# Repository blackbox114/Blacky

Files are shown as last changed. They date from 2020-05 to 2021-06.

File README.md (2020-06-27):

# Blacky

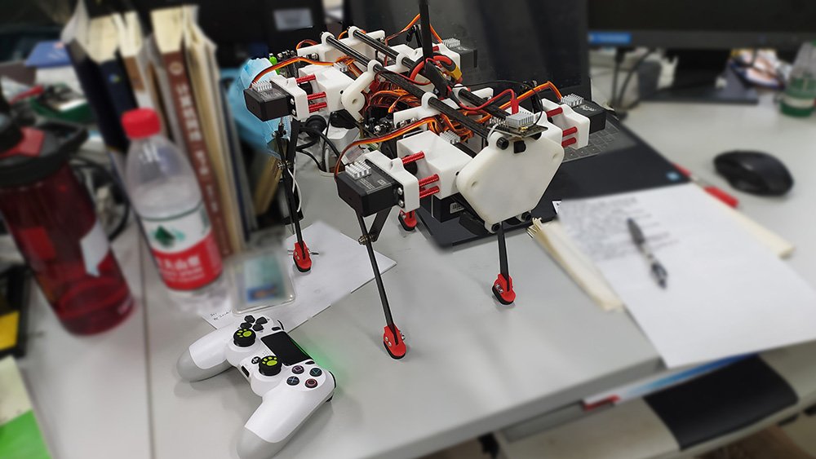
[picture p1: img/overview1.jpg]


The project originated from [StanfordPupper](https://github.com/stanfordroboticsclub/StanfordQuadruped) ，Designed to improve some structures to achieve better performance, and learn the algorithms used in the pupper. Thanks to Nathan and his team for their work, it ’s really great. Feel free to [raise an issue](https://github.com/blackbox114/blacky/issues/new/choose)  or email me at chen.junfei@nexuslink.cn

### Bilibili

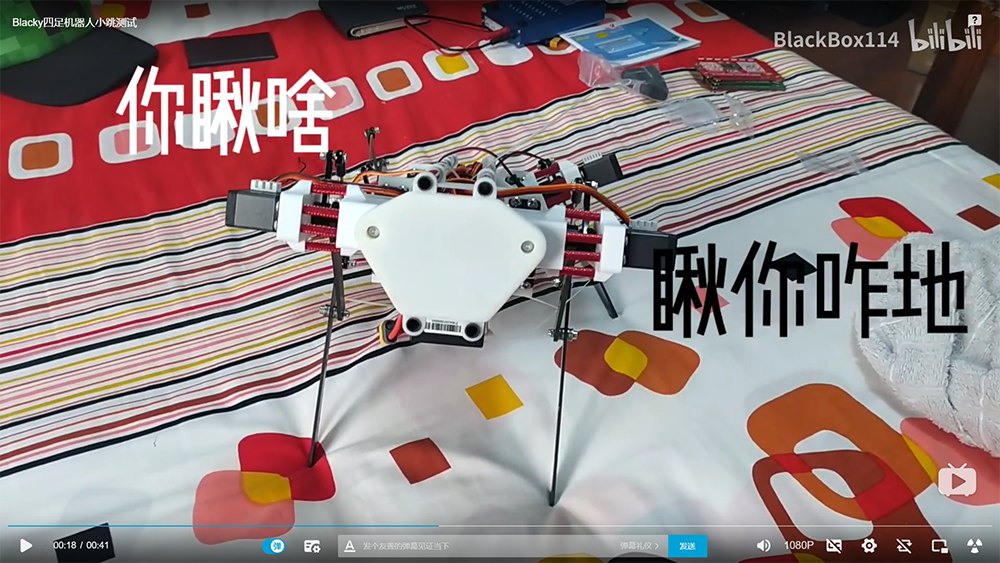
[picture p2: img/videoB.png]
(https://www.bilibili.com/video/BV1B54y1D7uH/)


### YouTube

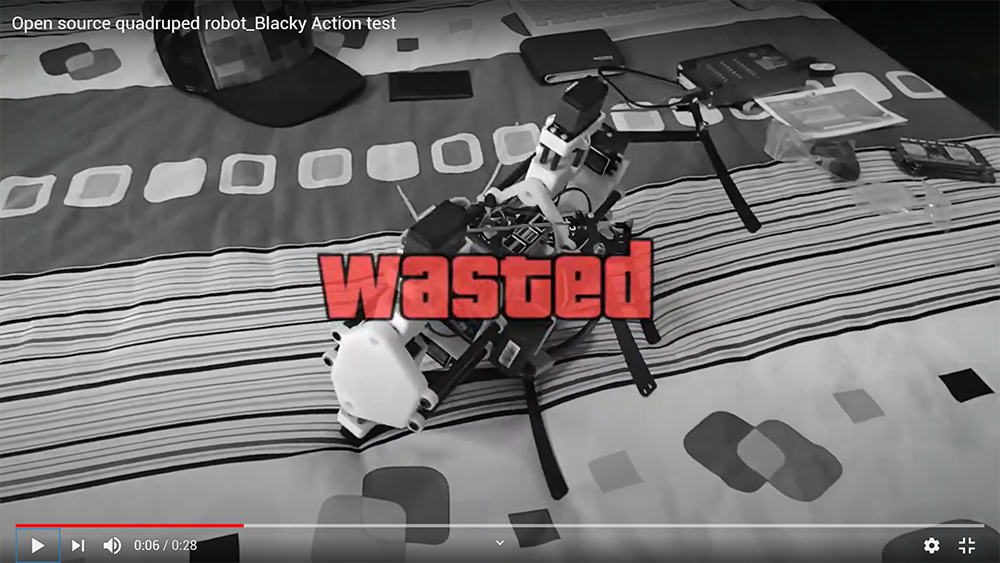
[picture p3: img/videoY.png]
(https://www.youtube.com/watch?v=VOyvlLOYNlo)


ps:正在本地化和推出中文教程 

### current condition 
Now calibrating hip and leg.

### Overview
12Dof, use pi4 and CLS6336servo.

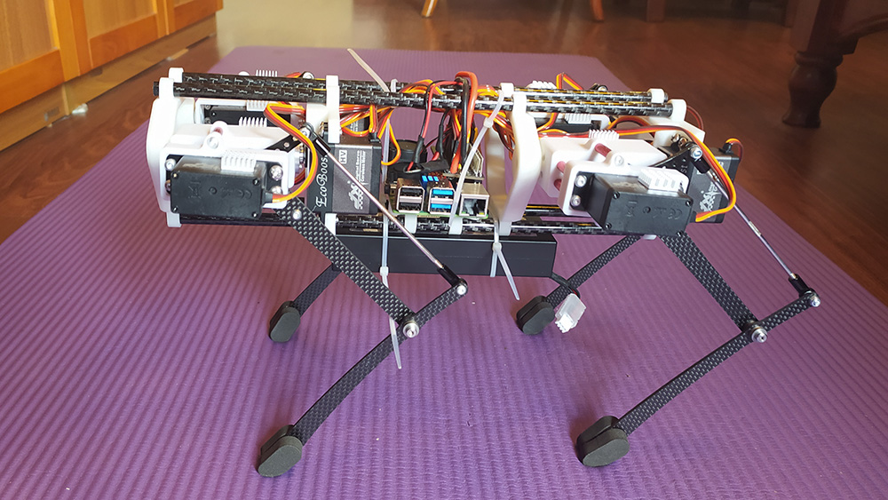
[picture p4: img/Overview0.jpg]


### PCB
Added cooling fan, the next step is to integrate the power chip to the board. Find Gerber on this repo , or Visit [this link](https://easyeda.com/blackboxx114/arduboy) .

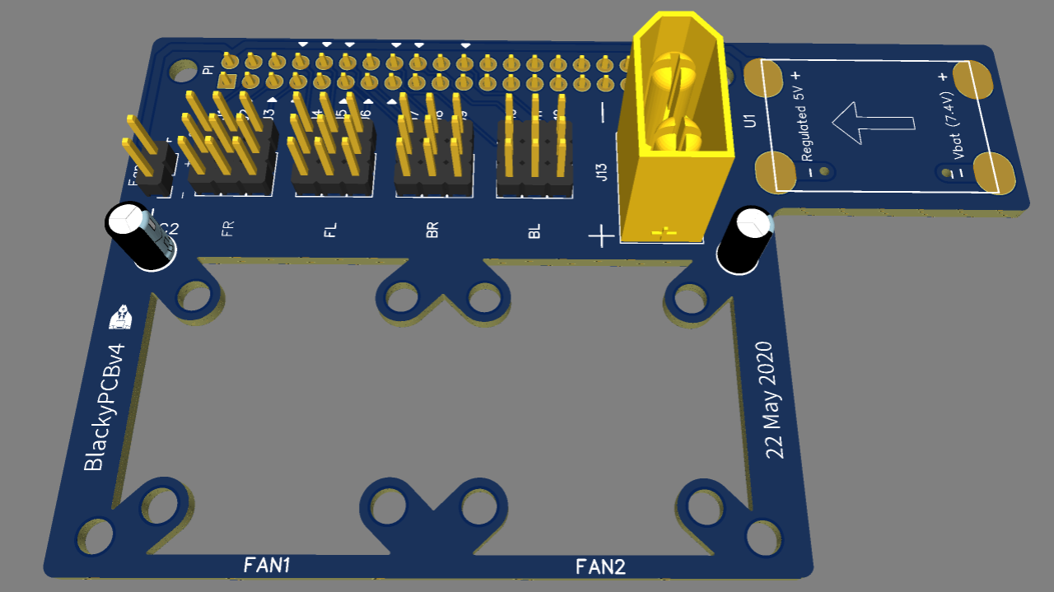
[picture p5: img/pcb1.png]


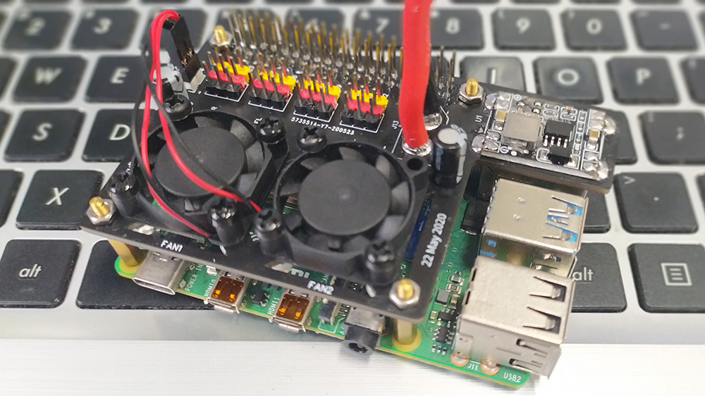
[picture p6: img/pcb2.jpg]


### New Structure
curing SLA print+Carbon fiber tube, Lighter and easy to install other modules.  boots.jpg



PLA3Dprint boots+M3 Sponge mat

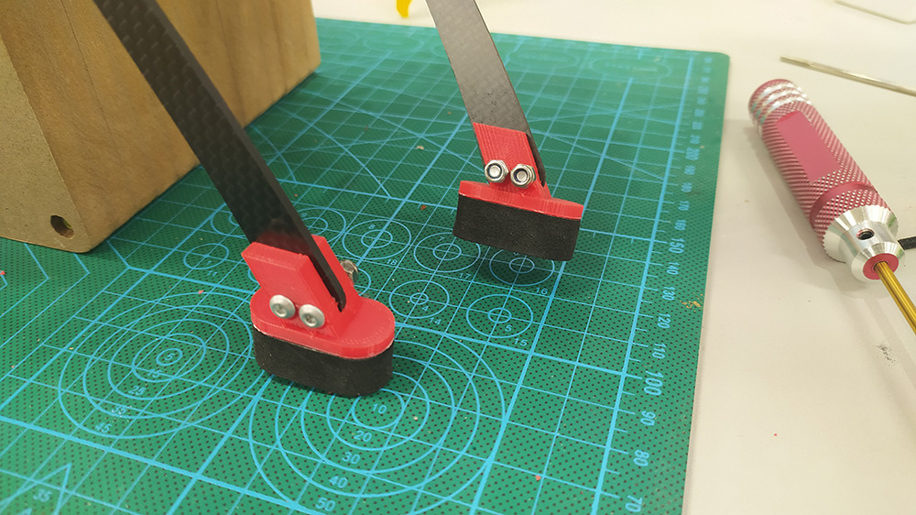
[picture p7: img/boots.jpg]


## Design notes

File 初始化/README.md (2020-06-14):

# 树莓派初始化
### 修改wifi配置
请在*Blacky\初始化\appliance\etc\wpa_supplicant*中添加自己的wifiSSID和PSWD，具体格式参考：

ssid：LBm

pswd：11111111

```text
network={
        ssid="LBm"
        psk="11111111"
}
```

### 覆盖文件
烧录镜像完成后，请直接将本仓库复制粘贴到boot文件夹，覆盖重复的文件。

### 启动和ssh

正常上电启动。请提供稳定网络进行初始化，初始化需要一些时间，初次初始化可以外界屏幕和键盘观察进度。ok后可直接ssh进入。请按照提示修改密码和ip

### 进入写模式
```shell
rw
```
### 换源
```shell
$sudo sed -i 's|raspbian.raspberrypi.org|mirrors.ustc.edu.cn/raspbian|g' /etc/apt/sources.list

$sudo sed -i 's|//archive.raspberrypi.org|//mirrors.ustc.edu.cn/archive.raspberrypi.org|g' /etc/apt/sources.list.d/raspi.list

$sudo apt-get update
```
### pqi更新pip源
```shell
$pip install pqi

$pqi

$pqi use ustc
```
### 自动对时
```shell
$sudo date  --s="2020-11-08 20:42:00"

$sudo apt-get install ntpdate 
```
### 更换为国内对时服务器
```shell
$sudo nano /etc/ntp.conf
将
pool 0.debian.pool.ntp.org iburst
pool 1.debian.pool.ntp.org iburst
pool 2.debian.pool.ntp.org iburst
pool 3.debian.pool.ntp.org iburst
更换为
server 1.cn.pool.ntp.org iburst
server 2.cn.pool.ntp.org iburst
server 3.cn.pool.ntp.org iburst
server 0.cn.pool.ntp.org iburst
```
### 下载项目文件
```shell
$git clone https://github.com/stanfordroboticsclub/StanfordQuadruped.git

$cd StanfordQuadruped
```
### 请注意这一步如果出现安装下载失败，请反复执行
```shell
$sudo bash install.sh
```
### 校准舵机
```shell
$sudo systemctl stop robot

$cd StanfordQudruped

$sudo pigpiod
```
#### 执行校准程序，每个都要校准，当它要求您将链接移动到水平位置时，您可能想知道到底什么使链接变为水平。答案是对齐每个链接的关节中心。例如，将上链节与水平方向对齐时，您需要使伺服花键和将上链节与下链节连接的螺栓之间的线尽可能水平。
```shell
$python3 calibrate_servos.py

$sudo systemctl start robot
```
### 检查状态
```shell
$sudo systemctl status robot
```

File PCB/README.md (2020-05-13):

# PCB
### 描述
目前pcb引出全部书没跑引脚，并直连舵机接口。vdd和gnd分别在两面铺铜供电，PCB附带风扇接口，但树莓派供电部分还没有整合【未完待续】
### 预览

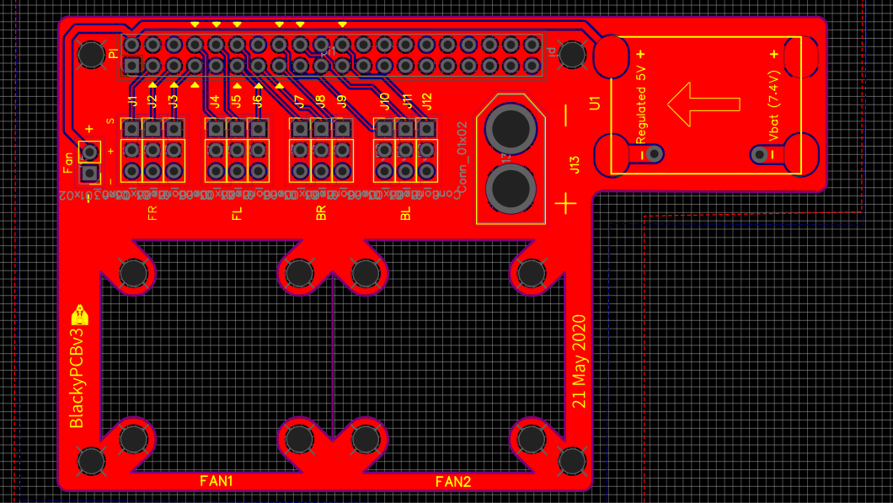
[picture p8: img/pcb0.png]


pcb0

### 打板参数
铜厚请选择2oz，低于此参数会导致供电不足，请注意这点

### 订购地址
嘉立创

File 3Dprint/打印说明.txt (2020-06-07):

Part name	  STL 名称	               数量
身体部分1	                           FrontFront.stl 	 1
身体部分2	                           FrontBack.stl	                 1
身体部分3	                           BackFront.stl	                 1
身体部分4		           BackBack.stl	                 1

树莓派+电池托架版本1         raspberry pad H	 1
树莓派+电池托架版本2         raspberry pad V	 1
		
髋关节内部	           HipInsideFDM.stl	 4
髋关节外壳	           HipOutsideFDM.stl	 4
减震足底	                           Boots.stl	                 4

采用PLA打印，速度80%，填充50%
采用树脂打印，参数默认即可

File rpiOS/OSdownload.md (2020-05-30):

### 镜像下载地址

https://slack-files.com/T0RAWRCGY-FQG7WTSBH-eb9549ed22

请采用此版本

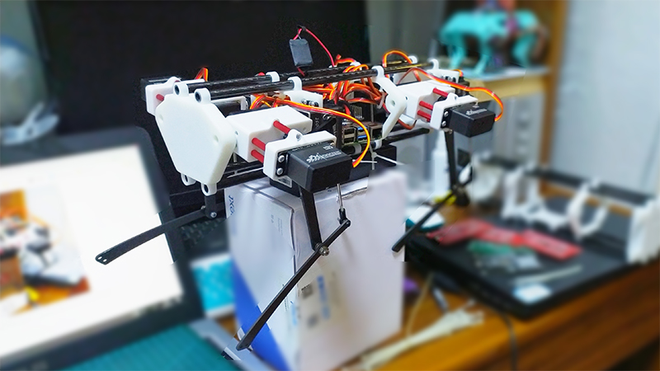
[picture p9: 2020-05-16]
img/title.jpg

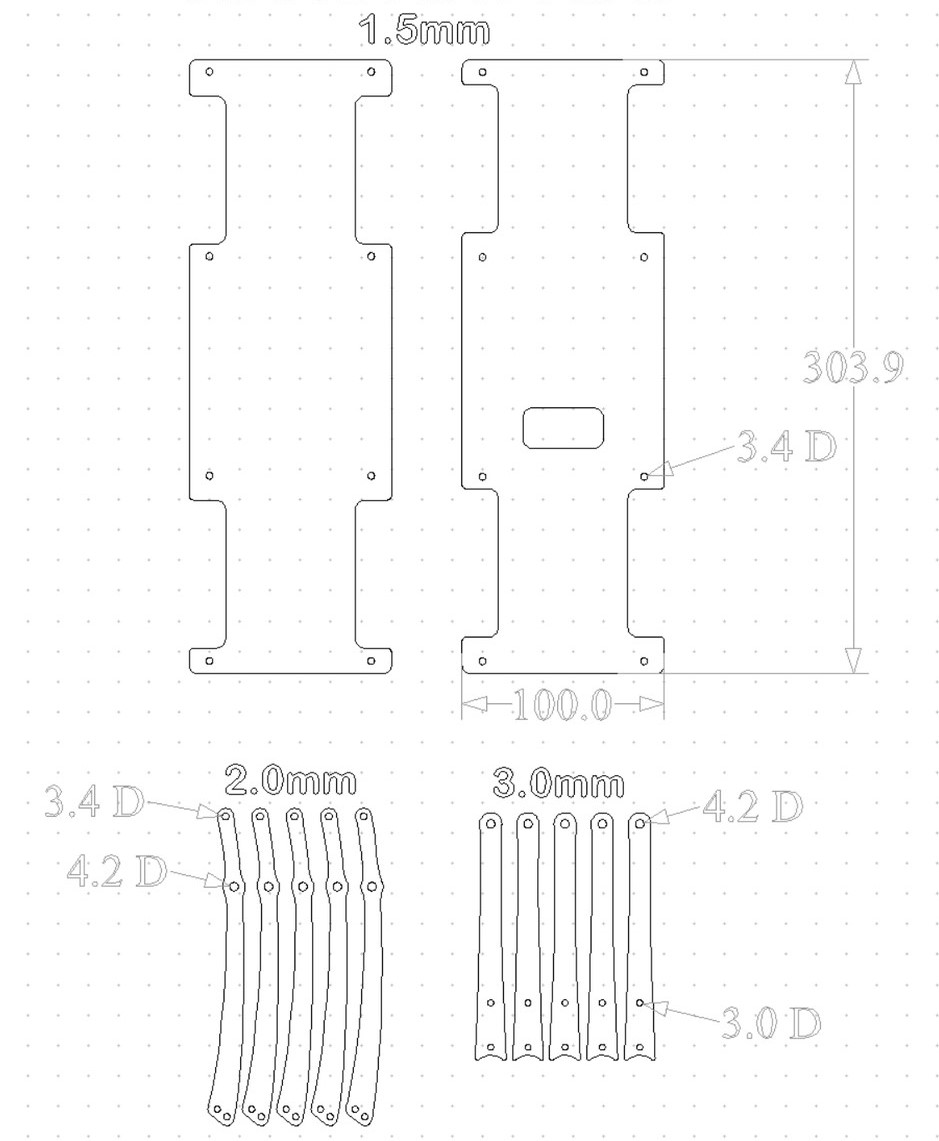
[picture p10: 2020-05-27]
carbonfiber/尺寸图示.jpg

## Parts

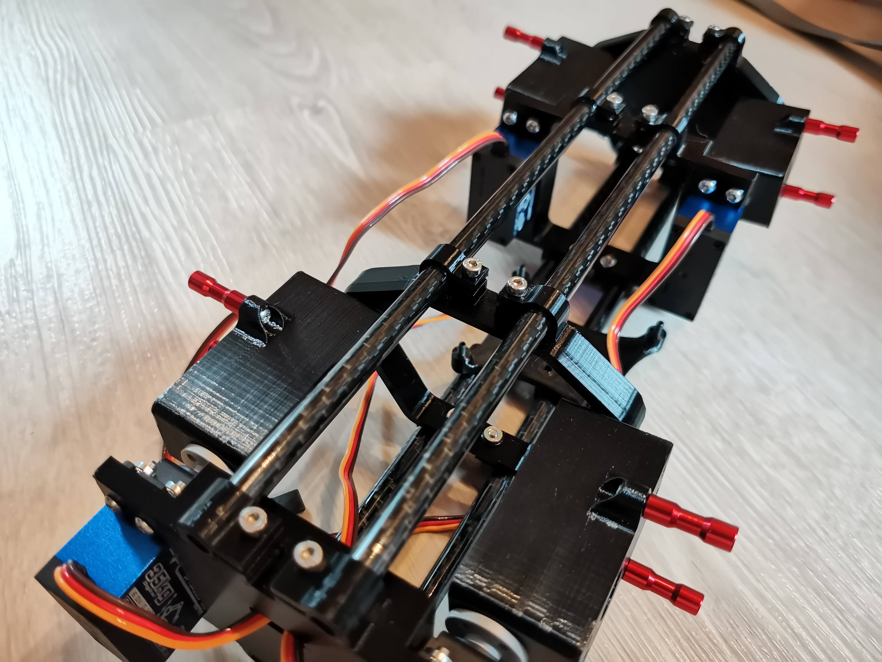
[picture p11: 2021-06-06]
3Dprint/screwed-body-parts.jpg

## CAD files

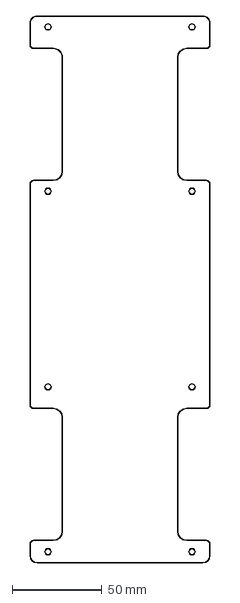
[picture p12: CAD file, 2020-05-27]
carbonfiber/底板_1个.dxf
100.0 x 303.9 mm

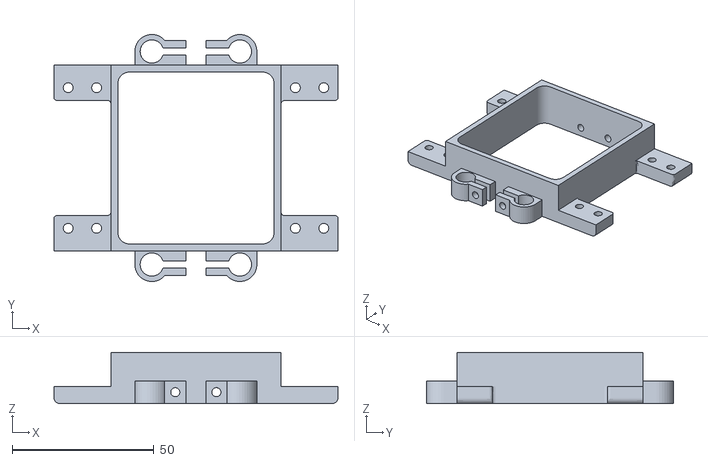
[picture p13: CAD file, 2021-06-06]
3Dprint/srew-front-back.stl
100.0 x 87.0 x 18.0

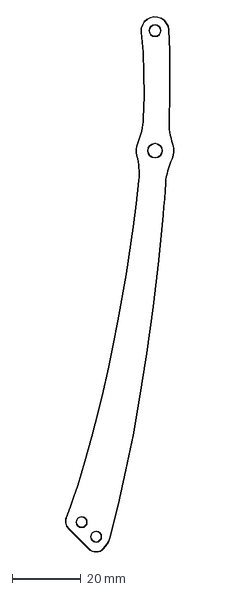
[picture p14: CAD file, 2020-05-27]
carbonfiber/小腿_5个.dxf
31.8 x 156.3 mm

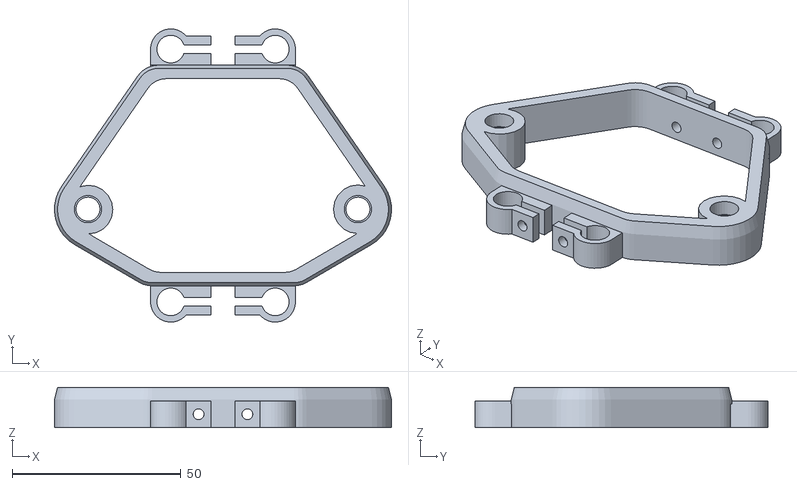
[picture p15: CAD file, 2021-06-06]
3Dprint/srew-back-front.stl
100.0 x 87.0 x 12.0

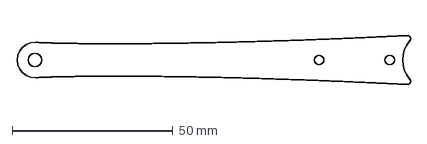
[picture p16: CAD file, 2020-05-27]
carbonfiber/大腿_5个.dxf
122.8 x 15.3 mm

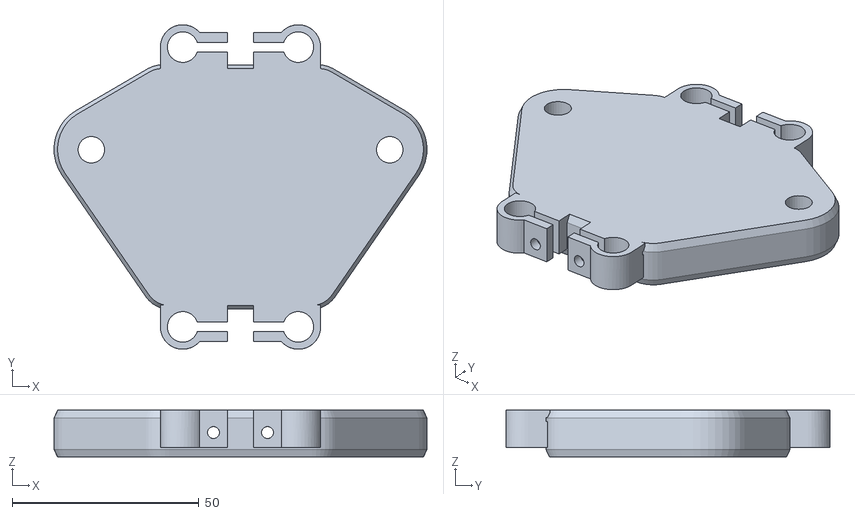
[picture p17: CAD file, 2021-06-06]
3Dprint/srew-front-front.stl
100.0 x 87.0 x 12.5

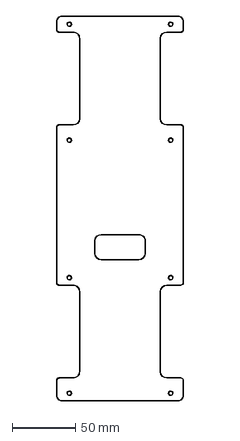
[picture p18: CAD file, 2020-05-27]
carbonfiber/顶板_1个.dxf
100.0 x 303.9 mm

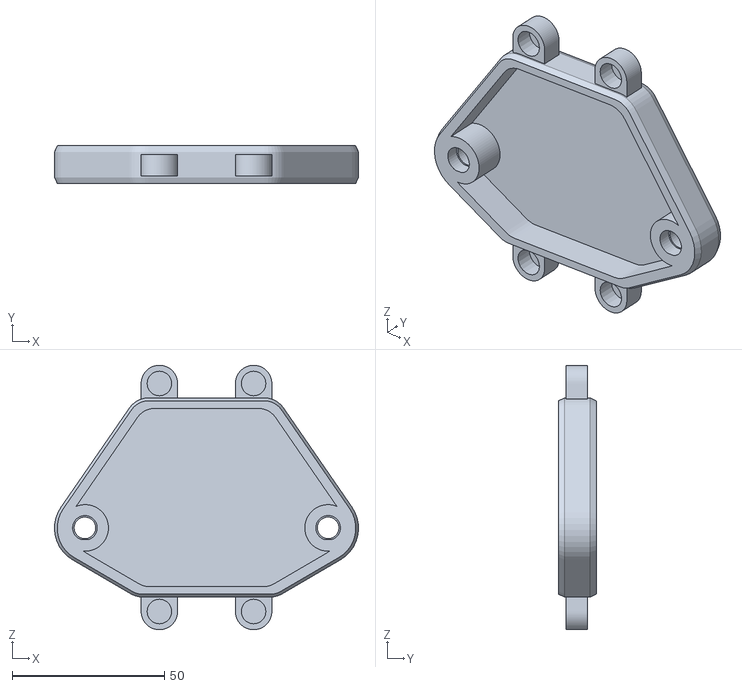
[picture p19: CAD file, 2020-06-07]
3Dprint/frontfront.stl
100.0 x 12.5 x 87.0

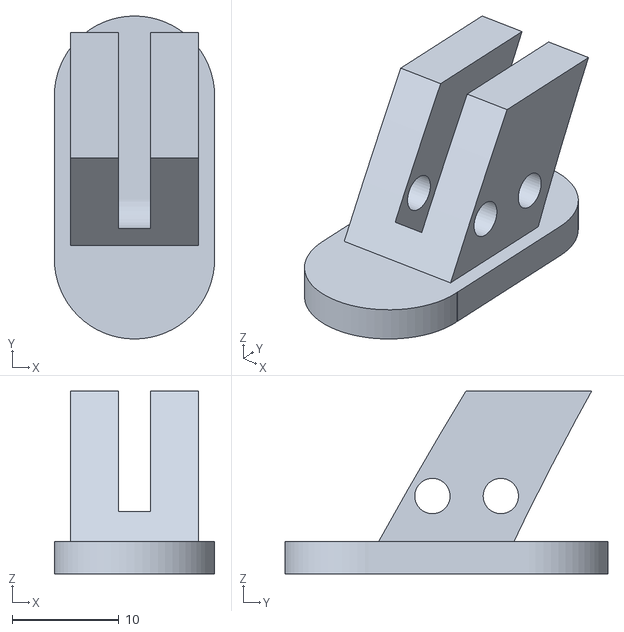
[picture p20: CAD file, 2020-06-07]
3Dprint/boots.stl
15.0 x 30.2 x 17.1

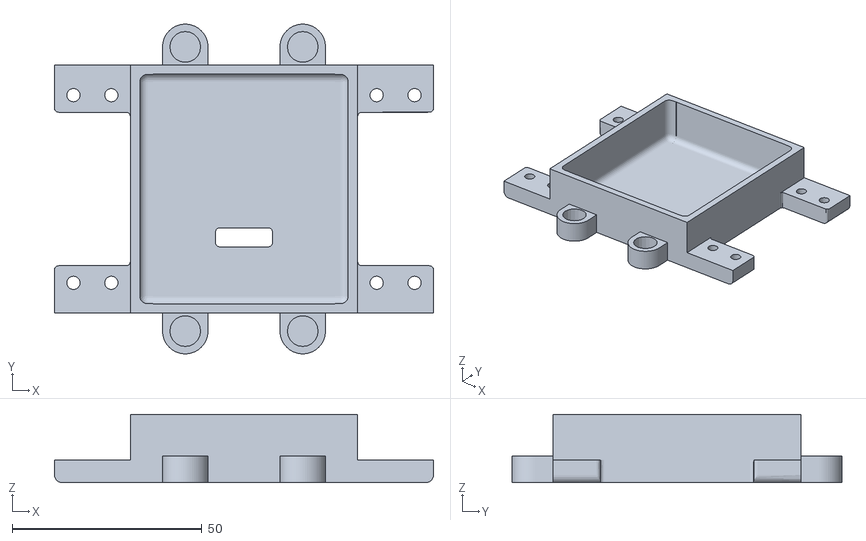
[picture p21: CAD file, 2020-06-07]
3Dprint/backback.stl
100.0 x 87.0 x 18.0

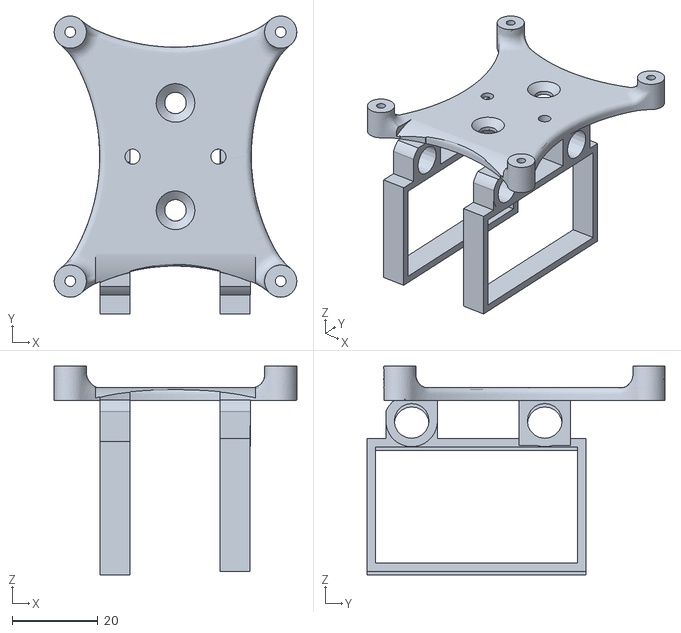
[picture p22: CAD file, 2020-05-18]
3Dprint/raspberry pad V B.stl
56.5 x 69.4 x 48.6

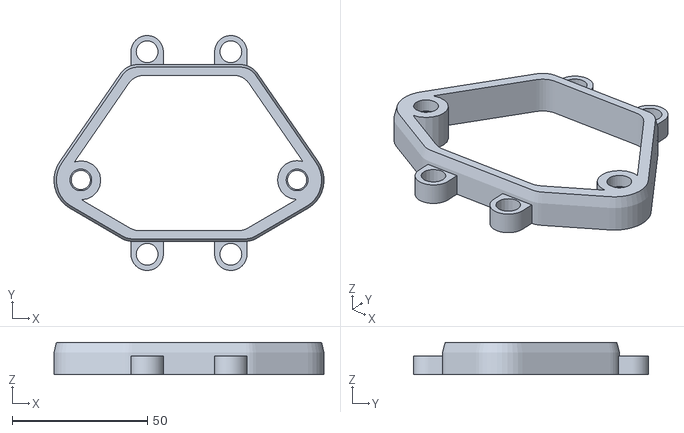
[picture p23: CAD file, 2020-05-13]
3Dprint/backfront.stl
100.0 x 87.0 x 12.0

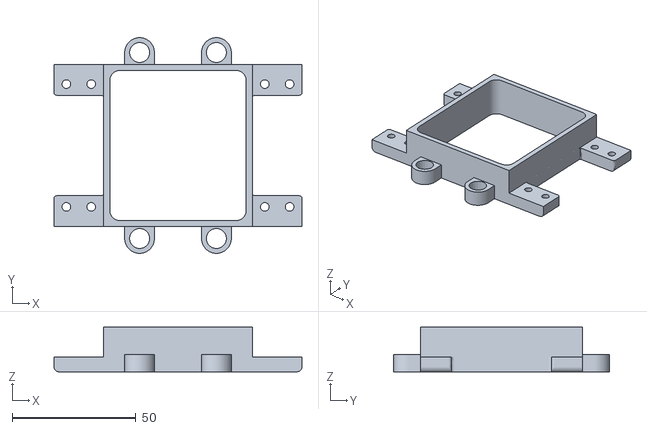
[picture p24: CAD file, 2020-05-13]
3Dprint/frontback.stl
100.0 x 87.0 x 18.0

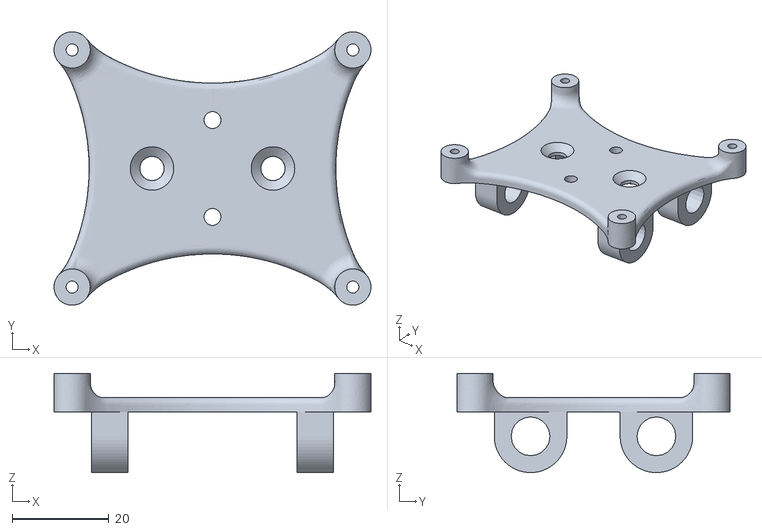
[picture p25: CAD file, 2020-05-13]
3Dprint/raspberry pad V.stl
65.5 x 56.5 x 20.5

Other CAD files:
3Dprint/raspberry pad H.stl
3Dprint/HipOutsideFDM.stl
3Dprint/HipInsideFDM.stl
3Dprint/screw-back-back.stl

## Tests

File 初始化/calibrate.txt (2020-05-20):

[ -8,   3,   0,   0], [ 16,  55, 45,  56], [-38, -68, -40, -38]

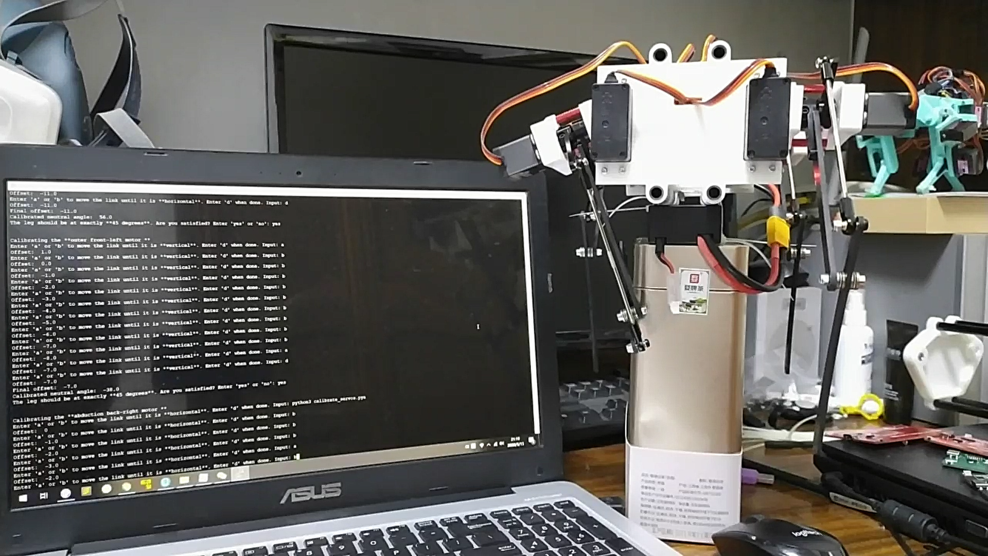
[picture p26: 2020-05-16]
img/calibrate.png

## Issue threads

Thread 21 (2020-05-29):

关于主控

a12t37, 2020-05-29:
请问主控使用的是raspberryPi4_4G吗？
操作系统是什么版本的？
性能如何，后续使用ROS系统需要更换主控吗？

a12t37, 2020-05-29:
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

blackbox114, 2020-05-29:
稍后我会上传一份我目前使用的镜像。目前使用这份镜像能够正常运行，其他的版本都需要修改一些设置。

 关于性能，目前树莓派4b的性能实际上已经足够，同时在处理ROS服务也是可以的，不过请将大部分运算放到你的上位机上。仅用树莓派作为ROS的某一终端执行操作和采集数据

如果不需要视觉的话会考虑制作树莓派zero版本，可以进一步降低成本

blackbox114, 2020-05-29:
> 请问主控使用的是raspberryPi4_4G吗？
> 操作系统是什么版本的？
> 性能如何，后续使用ROS系统需要更换主控吗？
请使用这个镜像在树莓派4上构建  https://github.com/blackbox114/Blacky/tree/div/rpisystem

blackbox114, 2020-05-29:
> 请问主控使用的是raspberryPi4_4G吗？
> 操作系统是什么版本的？
> 性能如何，后续使用ROS系统需要更换主控吗？

请访问 https://github.com/blackbox114/Blacky/tree/div/rpisystem 获取镜像，并在树莓派4上构建系统

blackbox114, 2020-06-02:
烧录镜像已经放在[此处]https://github.com/blackbox114/Blacky/tree/master/rpiOS) 。实际上测试发现直接下载2019-09-26-raspbian-buster-lite也是可以使用的

Closed 2020-06-02.

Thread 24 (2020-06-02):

关于打印件

zhansheng, 2020-06-02:
你好，打印件你是在哪里打印的，方便留个联系方式吗？

blackbox114, 2020-06-02:
打印件我是在淘宝上找到的一家店，搜“未来工厂”可以搜到。我这里的打印件重量低于210g，所以当时打印没收钱，只收了邮费，你可以去看看未来工厂还有没有这样的活动

zhansheng, 2020-06-02:
好的，谢谢

blackbox114, 2020-06-02:
不客气。另外，打印件适配的是8mm碳纤维管或铝管，长度300mm

Closed 2020-06-02.

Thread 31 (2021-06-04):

Provide carbon fibre rod length

LaryLee, 2021-06-04:
Hi,
could you please provide the length of the carbon fibre rod?

Thank you :)

blackbox114, 2021-06-04:
Hello！

The length of the carbon fiber rod is 30.

GoodLuck！

&nbsp;
&nbsp;
------------------&nbsp;Original&nbsp;------------------
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

LaryLee, 2021-06-04:
Thank you!

Closed 2021-06-04.

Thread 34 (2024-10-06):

请教一些问题

Maker1201, 2024-10-06:
您好，我关注了您的GitHub分享，我最近也做了一个四轮足机器人，想请教一些问题，希望您有空了给我一下回答。
1.您的那个pcb板是用树莓派4b直接驱动的pwm嘛，还是树莓派做上位机做的驱动板啊
2.另外我还需要接四个编码电机，您有什么好的建议嘛，是直接用树莓派驱动还是另外接一个电机驱动板。
3.我这个项目主要还是想做机器人建图用的是激光雷达。是直接做控制还是引入机器人操作系统呢

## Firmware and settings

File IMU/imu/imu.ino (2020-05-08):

/*
根据BNO080库编写
 在400kHz I2C上需要大约1ms的时间来读取传感器的记录
 loop里面在进行循环
 硬件连接：
 将I2C引脚从BNO080的I2C连接到Teensy。用短的microUSB->USB电缆将Teensy连接到R树莓派。
库地址https://github.com/sparkfun/SparkFun_BNO080_Arduino_Library
*/

#include <Wire.h>

#include "SparkFun_BNO080_Arduino_Library.h"
BNO080 myIMU;

long last_print = micros();

void setup()
{
  Serial.begin(500000);
  Serial.println();
  Serial.println("BNO080 IMU 监测中");

  Wire.begin();
  if (myIMU.begin() == false)
  {
    Serial.println("没有在默认的I2C接口检测到BNO080 。请检查线路是否通畅");
    while (1);
  }
  Wire.setClock(400000); //把I2C速度拉到400kHz
  //最快反馈速度400Hz -> 大约2.5ms给书没跑传输一次值
  myIMU.enableRotationVector(10); //每10ms更新一次数据
  Serial.println(F("启用"));
  Serial.println(F("输出数据格式为  i, j, k, real, accuracy"));
}

void loop()
{
  if (myIMU.dataAvailable() == true)
  {
    float quatI = myIMU.getQuatI();
    float quatJ = myIMU.getQuatJ();
    float quatK = myIMU.getQuatK();
    float quatReal = myIMU.getQuatReal();
    Serial.print(quatReal, 4);
    Serial.print(F(","));
    Serial.print(quatI, 4);
    Serial.print(F(","));
    Serial.print(quatJ, 4);
    Serial.print(F(","));
    Serial.print(quatK, 4);
    Serial.println();
  }
}

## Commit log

2020-05-11 git update
    [HipInsideFDM.stl, HipOutsideFDM.stl]
2020-05-14 Print parameters
2020-05-18 Create raspberry pad V B.stl
    [raspberry pad V B.stl]
2020-05-23 update pcb file
2020-06-07 upload stl
    [backback.stl, boots.stl, frontfront.stl]
2020-06-08 update new gerber
2021-06-06 Body parts with screws to clamp down on carbon fibre rods
    [screw-back-back.stl, srew-back-front.stl, srew-front-back.stl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]
